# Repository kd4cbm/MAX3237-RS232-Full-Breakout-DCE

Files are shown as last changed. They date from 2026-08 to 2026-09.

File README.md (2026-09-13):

# MAX3237 Full Breakout Board (DCE)

A 2-layer breakout board that converts a 3.3V TTL UART into true RS-232 levels
using the [Maxim/TI MAX3237](https://www.analog.com/media/en/technical-documentation/data-sheets/max3222-max3241.pdf),
wired as **DCE** (modem-side) so it plugs directly into a DTE (terminal/PC)
with a standard straight-through DE-9 cable. Built as the RS-232 front end
for the [RetroWiFiModem](https://github.com/kd4cbm/Zimodem-VFD) project's
ESP32-S3 port, but usable standalone anywhere a 3.3V-logic device needs a
real RS-232 port.

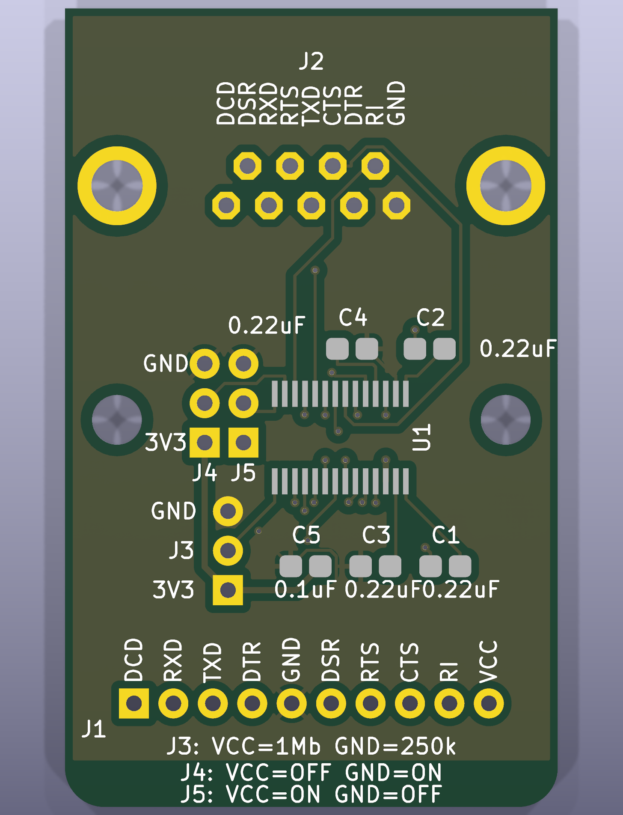
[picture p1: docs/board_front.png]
Front

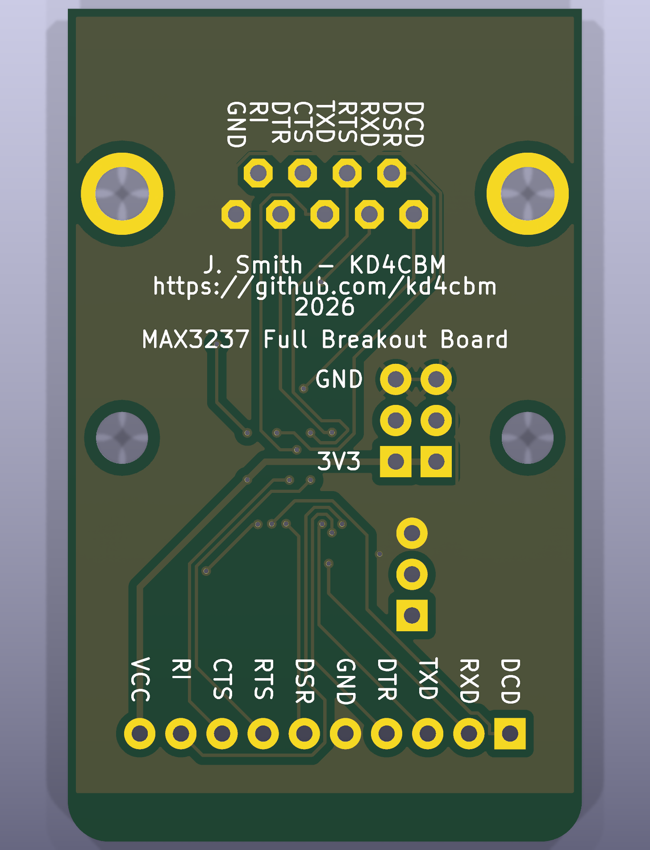
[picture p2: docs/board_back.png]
Back


## ⚠ Known issue in previously-manufactured boards: J2 footprint was rotated 180°

Boards ordered from `main` **before this fix** have the J2 DE-9 footprint
rotated 180° from correct relative to the schematic - both left-right *and*
which physical row (the 5-pin row vs. the 4-pin row) sits nearer the board
edge are affected. The pads and copper are internally consistent with each
other and with the net names below, but the physical pin layout does not
match the standard DE-9 pinout - if you plug a straight-through cable into
an affected board, you will connect to the wrong signal on every pin except
5 (GND, which sits on the connector's center axis).

This shipped in two stages. An initial fix (commit `0a0792f`) corrected the
left-right pin order, verified at the time against KiCad's own standard
`Connector_Dsub` library footprint - but that check only compared left-right
order and missed that the two pin rows were *also* swapped front-to-back, so
boards built from that revision alone still had the 5-pin row nearer the
board edge instead of the 4-pin row. That was caught on a second, closer
comparison against the same trusted footprint (this time checking full 2-D
pad geometry, not just left-right rank) and against the actual net-name
silkscreen labels, and is corrected as of commit `1042daa` - J2 rotated the
remaining 180°, all copper ripped and rerouted again.

**If you already have a board built from `main` before this revision** -
whether it predates the first fix or only the second - do not assume the J2
pins match the table below. Either replace the board with one built from
this revision, or trace out each pin with a meter against the
schematic/netlist and build a corrected cable or adapter for that specific
board before relying on it.

A related but separate defect existed only in git history, never manufactured:
commit `1042daa`'s row-orientation fix moved the J2 *pads* to the correct
physical location but repositioned the *silkscreen net labels* using a wrong
assumption about which pad number carried which net, so 8 of the 9 printed
labels ended up swapped with their opposite-row counterpart (e.g. the pad
that actually carries DCD was labeled "GND", and vice versa) - the copper
and nets themselves were correct the whole time, only the printed text was
wrong. Fixed as of the current revision; the silkscreen now matches the
[J2 pinout](#connectors) below pin-for-pin.

## Connectors

**J1 - TTL header** (10-pin, 2.54mm, 3.3V logic side)

| Pin | 1 | 2 | 3 | 4 | 5 | 6 | 7 | 8 | 9 | 10 |
|---|---|---|---|---|---|---|---|---|---|---|
| Signal | DCD | RXD | TXD | DTR | GND | DSR | RTS | CTS | RI | VCC |

**J2 - DE-9 female** (RS-232 side, DCE pinout - wire straight through to a DTE)

Standard DE-9 DCE pinout: DCD(1), RXD(2), TXD(3), DTR(4), GND(5), DSR(6),
RTS(7), CTS(8), RI(9).

## Function jumpers

Each jumper is a 3-pin header: pin 1 (square pad) = +3.3V, pin 3 (round pad)
= GND, pin 2/center = the signal. Bridge pins 1-2 or 2-3 with a shunt to pick
a state.

| Jumper | Function | VCC position | GND position |
|---|---|---|---|
| J3 | MBAUD (data rate select) | MegaBaud mode, up to 1Mbps | Normal mode, up to 250kbps |
| J4 | EN&#772; (receiver enable, active-low) | Receivers disabled (high-Z) | Receivers enabled (normal) |
| J5 | SHDN&#772; (shutdown, active-low) | Normal operation | Shutdown, <1uA supply current |

## Capacitors

Per the MAX3237 datasheet's Table 2, worst-case row (VCC = 3.3V &plusmn;10%):

- **C1, C2, C3, C4** - 0.22uF, charge-pump/reservoir caps
- **C5** - 0.1uF, VCC bypass (the standard smaller bypass value, independent
  of the charge-pump table)

All five are 0805 ceramic MLCC. See [Assembly](#assembly-jlcpcb-pcba) for
sourcing notes.

## Board

- 2-layer, 31.75 x 41.93mm, JLCPCB-manufacturable (checked against their
  published capabilities: trace/clearance, via annular ring &ge;0.18mm,
  silkscreen &ge;1.0mm/0.15mm, hole-to-hole spacing, copper-to-edge)
- GND poured on both copper layers
- Two M3 mounting holes, X-aligned with the DE-9 connector's own built-in
  mounting/jackscrew posts so both hole pairs share one centerline
- Keepout zones around all four plated mounting holes (the 2 board holes +
  the DE-9's own 2 hardware holes) so a copper pour can't bridge to a
  grounded chassis screw
- Routed with [Freerouting](https://github.com/freerouting/freerouting) 2.3.0

## Assembly (JLCPCB PCBA)

This board is set up for **SMD-only PCBA**: JLCPCB places U1 and C1-C5 (all
SMD); the DE-9 socket, TTL header, and 3 jumpers are through-hole and ship
loose for hand-soldering afterward - they're simple, forgiving parts to
solder by hand, and this keeps assembly cost and lead time down versus
sourcing THT parts for machine placement.

Files in [`hardware/`](hardware/):

- `kicad/` - full KiCad 10 project (schematic + PCB)
- `gerbers/Gerbers_*.zip` - Gerber + Excellon drill files, ready to upload. **This zip is a generated
  snapshot, not kept in sync automatically** - it sat stale from rev 4 through rev 8 while the PCB
  source moved on. Regenerate it (`kicad-cli pcb export gerbers` + `pcb export drill`) any time
  `hardware/kicad/*.kicad_pcb` changes, before ordering
- `CPL_SMD.csv` - placement/position file (SMD parts only)
- `BOM_PCBA_JLCPCB.csv` - PCBA bill of materials (SMD parts only). U1's LCSC
  part number (`C2671155`, MAX3237EIPWR) is verified against LCSC's own
  listing. The capacitor rows intentionally list full specs (0805, X7R,
  value, &ge;16V) with **no** LCSC number - JLCPCB's basic-parts catalog is a
  live, dynamic search that isn't reliably scriptable, and these are common
  enough values that matching one at checkout takes seconds. Verify current
  stock/pricing before ordering rather than trusting a number pinned months
  earlier.
- `BOM_full.csv` - every part on the board, including the through-hole
  connectors, for your own reference/hand-assembly shopping list

**Before ordering, check U1's orientation in JLCPCB's assembly preview.**
`CPL_SMD.csv` currently has U1 at rotation 180, verified against JLCPCB's
own preview tool - but this value depends on which specific LCSC library
part they match to the MAX3237EIPWR footprint (`C2671155`), and that
match/library entry can change over time. If U1 looks rotated in their
preview, JLCPCB's placement review UI lets you rotate a part directly and
save the correction - no need to regenerate any files for a one-off order.
A quick way to confirm correct placement without knowing the datasheet by
heart: pin 1 is on the net `/MAX-C2+`, i.e. it should land right next to
**C2**'s own pad (not C4, and not on the opposite pin row).

## Revision history

| Rev | Notes |
|---|---|
| 0 | Original layout, master reference |
| 1 | Pre-routing checkpoint (placement + keepouts finalized) |
| 2 | Post-routing checkpoint (Freerouting output, traces only) |
| 3 | Added GND pour, widened VCC traces |
| 4 | JLCPCB via/silkscreen compliance fixes, RXD/TXD silkscreen wording |
| 5 | Partial fix for mirrored J2 (DE-9) footprint - corrected left-right pin order only; row-to-edge assignment was still wrong (see rev 6) |
| 6 | Completed the J2 (DE-9) footprint fix: rotated the remaining 180° so the 4-pin row is nearer the board edge; full copper rip/reroute/repour; see [Known issue](#-known-issue-in-previously-manufactured-boards-j2-footprint-was-rotated-180) above |
| 7 | Cleared two starved-thermal DRC warnings (J2/J3 GND pads set to solid zone connection); no pad or copper changes |
| 8 | Full copper rip/reroute/repour (no pad changes) to clean up scattered clearance-void shapes left by earlier auto-routes; added a dedicated `Power` net class so `+3.3V` routes at 0.4mm instead of the 0.2mm signal-trace default |
| 9 | Regenerated `gerbers/Gerbers_*.zip` and the drill file, which had never been updated past rev 4 - anyone ordering from the old zip would have gotten the original mirrored-J2 board regardless of every PCB-source fix above. Verified against the drill file directly: the 4-pin row's holes now fall closer to the board edge than the 5-pin row's, and every component-hole count (J1/J2/J3-5 pads, both mounting-hole types) matches the pre-fix file exactly - only the via count differs, as expected from a fresh autoroute. `CPL_SMD.csv` and the BOM files were checked and are still correct as-is (no SMD part moved or changed value) |
| 10 | **Current** - Fixed J2's silkscreen net labels: 8 of the 9 (every one but TXD, which sits on the axis of symmetry) were mirror-swapped with their opposite-row counterpart, a mistake introduced when the labels were repositioned during the rev 6 row-orientation fix - the *pads* moved to the correct physical location then, but the labels were repositioned using a wrong net-to-pad-number assumption - the silkscreen now matches the [J2 pinout](#connectors) above pin-for-pin. No copper/pad changes; Gerbers and drill regenerated since the silkscreen layer changed |

## License

Hardware design files (schematic, PCB, Gerbers) are released under
[CERN-OHL-W v2](https://cern-ohl.web.cern.ch/) - a weakly-reciprocal open
hardware license: you're free to use, modify, and manufacture this design,
including commercially; modifications to these design files themselves stay
open, but boards built from them (or your own separate designs that merely
use this one) don't inherit that obligation. See [LICENSE](LICENSE).

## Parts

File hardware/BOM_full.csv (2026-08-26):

Designator | Value | Footprint | Qty
C1-C4 | 0.22uf | Capacitor_SMD:C_0805_2012Metric | 4
C5 | 0.1uf | Capacitor_SMD:C_0805_2012Metric | 1
J1 | Conn_01x10 | Connector_PinHeader_2.54mm:PinHeader_1x10_P2.54mm_Vertical | 1
J2 | DE9_Socket | Connector_Dsub:DSUB-9_Socket_Horizontal_P2.77x2.84mm_EdgePinOffset9.40mm | 1
J3 | MBAUD | Connector_PinHeader_2.54mm:PinHeader_1x03_P2.54mm_Vertical | 1
J4 | ENABLE | Connector_PinHeader_2.54mm:PinHeader_1x03_P2.54mm_Vertical | 1
J5 | SHUTDOWN | Connector_PinHeader_2.54mm:PinHeader_1x03_P2.54mm_Vertical | 1
U1 | MAX3237EIPWR | MAX3237:PW28 | 1

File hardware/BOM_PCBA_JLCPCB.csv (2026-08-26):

Comment | Designator | Footprint | LCSC Part Number
MAX3237EIPWR | U1 | PW28 | C2671155
0.22uF 0805 X7R >=16V (basic-parts MLCC - select current match in JLCPCB parts search) | C1 | C_0805_2012Metric
0.22uF 0805 X7R >=16V (basic-parts MLCC - select current match in JLCPCB parts search) | C2 | C_0805_2012Metric
0.22uF 0805 X7R >=16V (basic-parts MLCC - select current match in JLCPCB parts search) | C3 | C_0805_2012Metric
0.22uF 0805 X7R >=16V (basic-parts MLCC - select current match in JLCPCB parts search) | C4 | C_0805_2012Metric
0.1uF 0805 X7R >=16V (basic-parts MLCC - select current match in JLCPCB parts search) | C5 | C_0805_2012Metric

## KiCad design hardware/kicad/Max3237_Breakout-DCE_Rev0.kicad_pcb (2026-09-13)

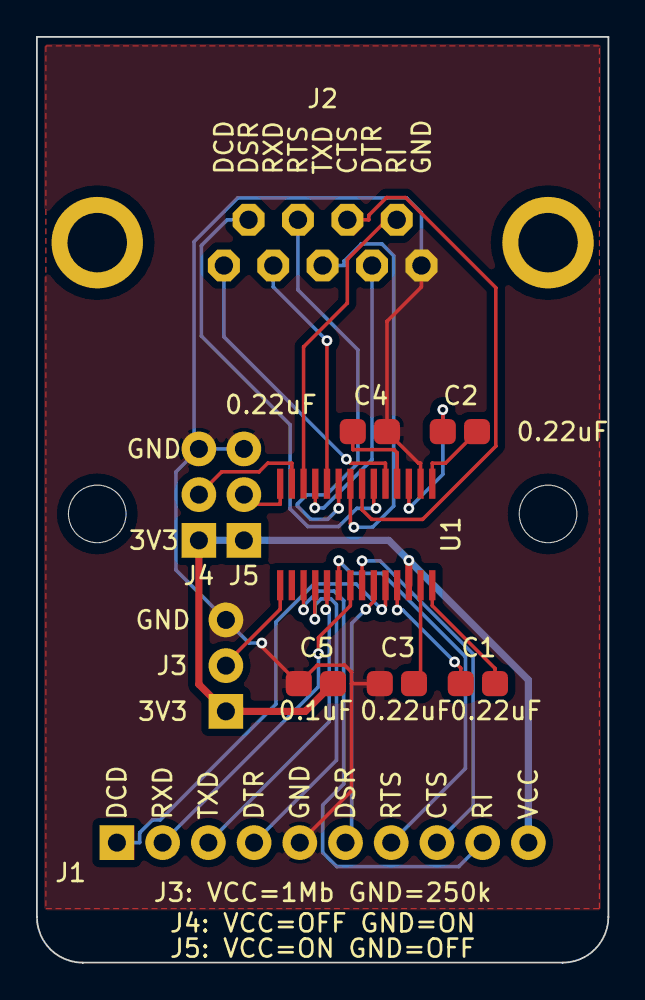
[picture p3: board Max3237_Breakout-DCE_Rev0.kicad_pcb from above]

Board: 2 copper layers, 31.8 x 51.4 mm, 13 parts (0 on the bottom side), 27 nets.

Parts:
C1, C2, C3, C4: 0.22uF; C_0805_2012Metric
C5: 0.1uF; C_0805_2012Metric
J1: TTL_HEADER; Header_1x10_P2.54mm_Round
J2: DE9_RS232; DE9_Female_THT
J3: MBAUD; Jumper_1x03_P2.54mm_Round
J4: ENABLE; Jumper_1x03_P2.54mm_Round
J5: SHUTDOWN; Jumper_1x03_P2.54mm_Round
MH1, MH2: MountingHole; MountingHole_3.2mm_M3
U1: MAX3237EIPWR; PW28

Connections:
+3.3V: C5.1, J1.10, J3.1, J4.1, J5.1, U1.26
/MAX-C1+: C1.1, U1.28
/MAX-C1-: C1.2, U1.25
/MAX-C2+: C2.1, U1.1
/MAX-C2-: C2.2, U1.3
/MAX-EN: J4.2, U1.13
/MAX-MBAUD: J3.2, U1.15
/MAX-SHDN: J5.2, U1.14
/MAX-V+: C3.1, U1.27
/MAX-V-: C4.2, U1.4
/RS232-CTS: J2.8, U1.7
/RS232-DCD: J2.1, U1.5
/RS232-DSR: J2.6, U1.6
/RS232-DTR: J2.4, U1.11
/RS232-RI: J2.9, U1.12
/RS232-RTS: J2.7, U1.9
/RS232-RXD: J2.2, U1.10
/RS232-TXD: J2.3, U1.8
/TTL-CTS: J1.8, U1.22
/TTL-DCD: J1.1, U1.24
/TTL-DSR: J1.6, U1.23
/TTL-DTR: J1.4, U1.18
/TTL-RI: J1.9, U1.17
/TTL-RTS: J1.7, U1.20
/TTL-RXD: J1.2, U1.21
/TTL-TXD: J1.3, U1.19
GND: C3.2, C4.1, C5.2, J1.5, J2.5, J3.3, J4.3, J5.3, U1.2

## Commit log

2026-08-26 Initial commit: MAX3237 RS-232 DCE breakout board (Rev4)
    KiCad project, schematic, PCB, Gerbers, and PCBA-ready BOM/CPL for a
    2-layer MAX3237-based RS-232 level shifter wired as DCE, built for the
    RetroWiFiModem project's ESP32-S3 port. JLCPCB-manufacturability verified
    (vias, silkscreen, clearances); routed with Freerouting 2.3.0.
    [BOM_PCBA_JLCPCB.csv, BOM_full.csv, Max3237_Breakout-DCE_Rev0.kicad_pcb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]
2026-08-26 Fix CPL_SMD.csv column format for JLCPCB upload
    kicad-cli's pos export uses KiCad's own generic CSV schema
    (Ref/PosX/PosY/Rot/Side, lowercase "top"/"bottom"), not JLCPCB's expected
    CPL schema. Verified against a real JLCPCB sample CPL file and their own
    KiCad help article: correct columns are Designator/Mid X/Mid Y/Layer/
    Rotation, with Layer as "Top"/"Bottom" and coordinates suffixed "mm".
    [CPL_SMD.csv]
2026-08-26 Fix U1 rotation in CPL_SMD.csv for JLCPCB's part library orientation
    Verified against JLCPCB's assembly preview: their matched library part
    for MAX3237EIPWR (TSSOP-28) has a different native 0deg reference than
    KiCad's footprint, so the CPL-computed rotation (270, correct on our own
    board) placed pin 1 90deg off in their system. Confirmed correct fix by
    checking pin 1's position against its own net (/MAX-C2+ = C2's own pad) in
    the preview - corrected rotation is 0, not 270, specifically for this part
    as matched in JLCPCB's library.
    [CPL_SMD.csv]
2026-08-26 Correct U1 rotation to 180 (previous 0 was the wrong direction)
    0 was wrong direction of the +-90 correction from 270 - it produced the
    right axis (horizontal, pins top/bottom) but put pin 1 on the wrong side.
    By elimination (TSSOP-28's outline only allows 0/180 for horizontal,
    90/270 for vertical, and 270 and 0 are both now confirmed wrong), 180 is
    the correct value. Not yet re-verified against JLCPCB's preview - pending
    user confirmation.
    [CPL_SMD.csv]
2026-08-26 Document the U1 CPL rotation gotcha in the README
    Future builders using JLCPCB PCBA will hit the same library-orientation
    mismatch we just worked through - document the fix and, more importantly,
    how to self-verify (pin 1 = /MAX-C2+, should land next to C2's pad) so it's
    a 10-second preview check instead of a failed-then-rediscovered order.
2026-09-12 Fix mirrored DE-9 (J2) footprint pinout, full copper rip/reroute/repour
    The custom MAX3237_DCE:DE9_Female_THT footprint had pins 1-5 and 6-9
    running in mirror-image order versus a real DE-9 connector - confirmed
    by direct pad-coordinate comparison against KiCad's own standard
    Connector_Dsub library part (the one the schematic's own Footprint
    field already claimed to use). Left uncorrected, a real connector
    soldered to this footprint would deliver: this board's DCD driver
    shorted onto the cable's real signal ground (pin 1<->5 swap), RXD
    fighting the peer's DTR driver, and CTS fighting the peer's RTS driver
    (pin 2<->4 and 7<->8 swaps) - genuine driver-vs-driver and
    driver-vs-ground contention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
    [Max3237_Breakout-DCE_Rev0.kicad_pcb]
2026-09-12 Document mirrored-J2 defect and fix in README
    Add a disclaimer for anyone with a board manufactured from main before
    this fix: the DE-9 (J2) footprint was mirrored 180 degrees, so physical
    pins don't match the standard DCE pinout on affected boards. Also add
    a revision history entry for the fix.
2026-09-12 Complete J2 footprint fix: correct row-to-edge orientation
    The previous fix (0a0792f) only corrected J2's left-right pin order.
    That check compared left-right pad rank against KiCad's standard
    Connector_Dsub footprint but never verified which physical row (5-pin
    vs 4-pin) sits nearer the board edge - so boards built from that
    revision alone still had the 5-pin row nearer the edge instead of the
    4-pin row, the same defect as the original manufactured board.
    Rotate J2 the remaining 180 degrees (full 2-D pad geometry now
    verified against the standard footprint, not just left-right rank,
    and cross-checked against the net-name silkscreen labels), reposition
    its silkscreen accordingly, and rip/re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
    [Max3237_Breakout-DCE_Rev0.kicad_pcb]
2026-09-12 Fix starved-thermal DRC warnings; drop populated-component renders
    Set J2 pad 5 and J3 pad 3 (both GND) to a solid zone connection
    instead of thermal relief - the auto-router's copper left too few
    clear directions for the required 2 thermal spokes at those two
    specific pads. No pad or trace geometry changed; DRC now reports 0
    violations beyond the pre-existing, unrelated footprint-library-path
    warnings (present even without any project fp-lib-table configured).
    Also revert docs/board_front.png and docs/board_back.png to bare-board
    renders. The 3D component models assigned in the previous commit
    didn't line up reliably across all the footprints (mixed footprint
    authoring conventions made per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
    [Max3237_Breakout-DCE_Rev0.kicad_pcb]
2026-09-12 Full rip/reroute/repour; add Power net class for a wider +3.3V trace
    Freerouting's fanout-via placement was scattering the mandatory
    0.5mm pour clearance halos somewhat differently on each reroute,
    which read as odd curved voids/slivers in the pour in a few spots
    (most visibly near C4). No DRC violation, but genuinely inconsistent
    with a hand-tuned layout. Ripped all copper and re-routed/re-poured
    from scratch (Freerouting, single-threaded, 100 passes, global
    strategy - same settings as before) rather than chase individual
    via placements.
    Also added a dedicated "Power" net class (0.4mm track width, vs the
    0.2mm Default) and assigned +3.3V to it, so the VCC rail routes
    noticeably wider than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
    [Max3237_Breakout-DCE_Rev0.kicad_pcb]
2026-09-12 Regenerate stale Gerbers/drill files - critical fix before reordering
    hardware/gerbers/Gerbers_Max3237_Breakout-DCE_Rev4.zip had not been
    regenerated since the very first commit. It predated every J2 fix
    this session (both the mirror and the row-orientation defect) - if
    this had been sent to the fab as-is, the second manufacturing run
    would have reproduced the exact same defective board regardless of
    how correct the .kicad_pcb source now is.
    Regenerated both the Gerbers and the Excellon drill file from the
    current board (kicad-cli pcb export gerbers/drill, same layer set and
    settings as the original export per its .gbrjob file). Verified
    directly against the new drill file, independent of t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
2026-09-13 Fix J2 silkscreen labels mirror-swapped by the row-orientation fix
    The rev 6 fix (commit 1042daa) rotated J2's pads 180 degrees to put
    the correct row nearer the board edge, then repositioned the 18
    silkscreen net-name text objects to follow. That repositioning used a
    hand-written net-to-X map built on a wrong assumption about which pad
    NUMBER carried which net (assumed pad 1 = GND, pad 5 = DCD; the
    footprint has always had pad 1 = DCD, pad 5 = GND, matching the
    standard DE-9 DCE order and the README's own pinout table).
    Net result: the pads and copper were always correct, but 8 of the 9
    printed labels ended up swapped with their mirror-image counterpart
    across the row's center pin (TXD, pi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
    [Max3237_Breakout-DCE_Rev0.kicad_pcb]
